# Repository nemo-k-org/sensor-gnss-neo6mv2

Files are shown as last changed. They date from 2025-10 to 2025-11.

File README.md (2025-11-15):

# Nemo-K location (GNSS) sensor for NEO 6M breakout board GY-NEO6MV2 

## Overview

This is Nemo-K board for ESP-01 and NEO 6M GNSS breakout board typically labelled
as `GY-NEO6MV2`. The board is widely available in stores selling Arduino-IoT related stuff.

The board sends GNSS information to Signal K server.

The board is designed to be used with ESP-01 microcontroller running Nemo-K firmware.

To build you need
 * The PCB
 * ESP-01S
 * NEO 6M GNSS breakout board
 * Four plastic hexagon motherboard spacers (length 8 mm, thread M2.5)
 * Eight M2.5 screws (length max 4 mm)
 * For external GPS antenna: pigtail from [Hirose U.FL](https://en.wikipedia.org/wiki/Hirose_U.FL) to typically
   SMA male/female

## Content

The repository contains schematics and PCB in KiCad 8.0 format. The footprint properties contains LCSC part numbers
used by [JLCPBC.com](https://jlcpcb.com). If present, the `sensor-gnssneo6mv2/production/` contains all necessary
files to order boards from JLCPCB. The production files can be easily re-created using
[KiCad Fabrication Toolkit](https://github.com/bennymeg/Fabrication-Toolkit).

The Nemo-K project is not affiliated or sponsored by JLCPCB. The project does not endorse JLCPCB.

## Changelog

2025-11-15 v3 - Revised after 1st proto
 * Changed power connector footprint to LCSC C5349550
 * Adjusted holes with GPS breakout board
 * Added test pads for voltage

2025-10-26 v2 - First prototype
 * First prototype was sent to production

## Copyright and License

The license and copyright can be found in the file `LICENSE`.

The license and copyright cover only the schematic diagram and the PCB design. It does not cover footprints and other
embedded elements or technical documentation which may or may not be covered by their own licenses.

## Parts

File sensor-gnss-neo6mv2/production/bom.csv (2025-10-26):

Designator | Footprint | Quantity | Value | LCSC Part #
CIN1 | 1210 | 1 | 10μF (50V) | C2918502
COUT1 | 1210 | 1 | 33μF (6.3V) | C531418
D1 | SOD-323_L1.7-W1.3-LS2.5-RD | 1 | D | C5174649
J1 | TerminalBlock_MetzConnect_Type086_RT03402HBLC_1x02_P3.81mm_Horizontal | 1 | PWR | C5349550
J2 | HDR-SMD_8P-P2.54-V-F-R2-C4-S7.1 | 1 | ESP-01S | C3975149
J3 | HDR-SMD_HX-PM2.54-1X4P-TP-YQ | 1 | NEO6M | C42379197
U1 | Texas_SIL0010A_MicroSiP-10-1EP_3.8x3mm_P0.6mm_EP0.7x2.9mm_ThermalVias | 1 | LMZM23601V3SILR | C2864948

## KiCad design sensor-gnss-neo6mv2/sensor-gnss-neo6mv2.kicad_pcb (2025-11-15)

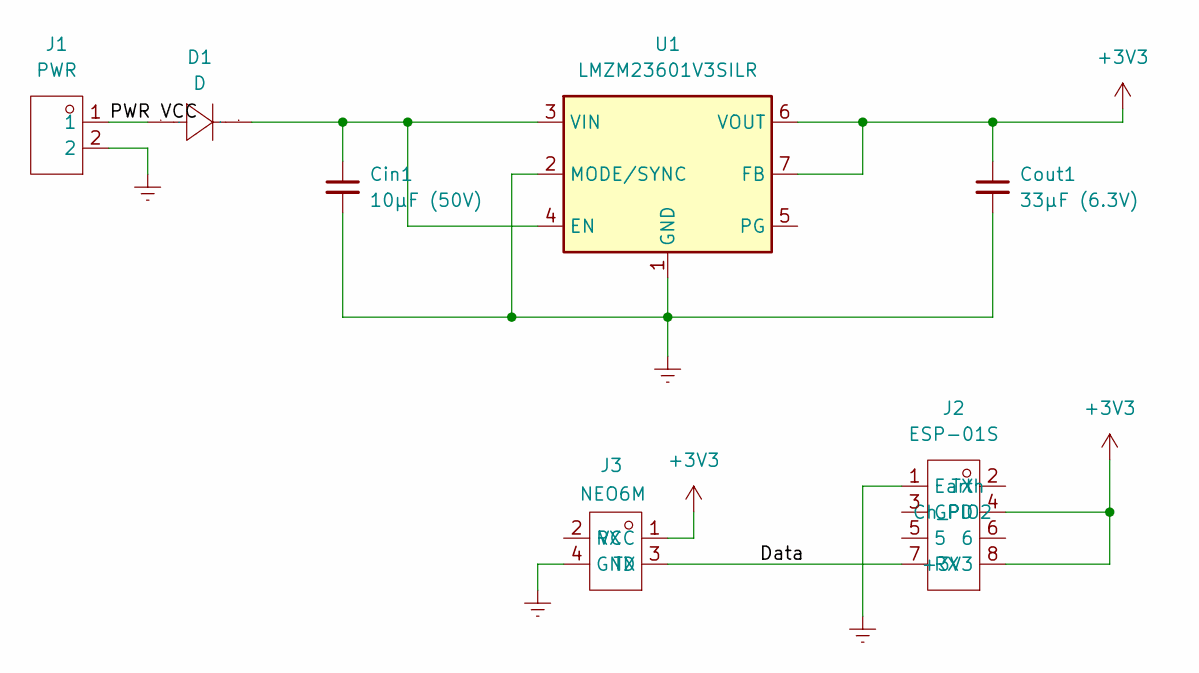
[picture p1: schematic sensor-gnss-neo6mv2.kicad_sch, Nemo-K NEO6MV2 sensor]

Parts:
Cin1: 10μF (50V); C_1210_3225Metric; LCSC C2918502
Cout1: 33μF (6.3V); C_1210_3225Metric; Mfg Part C3225X5R1A336MT0A0E; LCSC C531418
D1: D; SOD-323_L1.7-W1.3-LS2.5-RD; Manufacturer Part S7116-300A; LCSC Part Name S7116-300A
J1: PWR; CONN-TH_MX127S-3.81-02P-GN01-CU-Y-A; MPN OSTOQ053251; LCSC C5349550
J2: ESP-01S; HDR-SMD_8P-P2.54-V-F-R2-C4-S7.1; Mfg Part PM254-2-04-S-8.5; LCSC C3975149
J3: NEO6M; HDR-SMD_HX-PM2.54-1X4P-TP-YQ; Manufacturer Part HX PM2.54-1x4P TP-YQ; LCSC Part Name 间距:2.54mm 1x4P 立贴 (交错脚)
U1: LMZM23601V3SILR; Texas_SIL0010A_MicroSiP-10-1EP_3.8x3mm_P0.6mm_EP0.7x2.9mm_T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; MPN LMZM23601SILR; LCSC C2864948

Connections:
+3V3: Cout1.1, J2.4 (Ch_PD), J2.8 (+3V3), J3.1 (VCC), U1.6 (VOUT), U1.7 (FB)
/Data: J2.7 (RX), J3.3 (TX)
/PWR VCC: D1.2 (A), J1.1
Earth: Cin1.2, Cout1.2, J1.2, J2.1 (Earth), J3.4 (GND), U1.1 (GND), U1.2 (MODE/SYNC), U1.11 (GND)
unnamed: Cin1.1, D1.1 (K), U1.3 (VIN), U1.4 (EN)

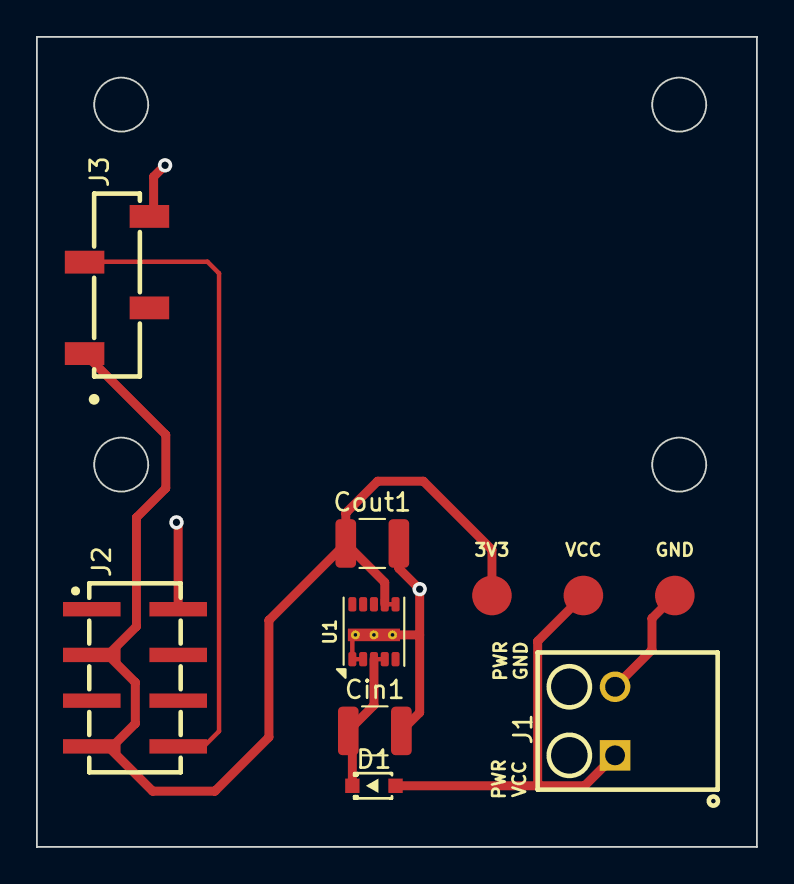
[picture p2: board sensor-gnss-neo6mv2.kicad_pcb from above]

Board: 2 copper layers, 40.0 x 45.0 mm, 7 parts (0 on the bottom side), 5 nets.

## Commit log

2025-10-09 First sketch of the schematics & PCB
    [sensor-gnss-neo6mv2.kicad_pcb, sensor-gnss-neo6mv2.kicad_sch]
2025-10-26 First prototype sent to production
    [bom.csv, designators.csv, positions.csv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]
2025-11-15 v3, revised based on first proto version
    [sensor-gnss-neo6mv2.kicad_pcb, sensor-gnss-neo6mv2.kicad_sch]
